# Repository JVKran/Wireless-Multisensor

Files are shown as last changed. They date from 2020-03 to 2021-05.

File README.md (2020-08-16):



# Wireless Multi-Sensor
ESP8266's are great! They are suited for an endless amount of fun projects. However, when you want to create small wireless modules, they are not so great; they consume way too much power and are pretty bulky. That's where this Wireless Multisensor comes into play; it features a sleep current of 50uA resulting in a lifetime of 3 years when using a CR123A battery! This is possible due to the use of an ATtiny85V with energy efficient components, sensors and libraries. Furthermore, it has a neat PCB and casing that really finishes it off!

All in all this sensor measures temperature, humidity, pressure, motion and illuminance. While that's already impressive, it's also possible to connect a switch to the JST-Connector to furter increase possibilities and tweakability. Hence one can connect a reed switch to determine the state of windows or doors, a button to toggle the lights in the room or a vibration sensor to detect movement of the sensor. These features will now be examined further.

## Features
### Years of worryless use
The ATtiny85V with a minimum voltage of 1.7V and a clock set at 1MHz paired with the abovely mentioned components and some very efficient libraries, results in a current draw of 52uA. Based on a 1500mAh CR123A this means the battery has got to be changed every (1500mAh / 0.052 =) 28800 hours or 1200 days or 3.3 years! Note that this depends on how often doors/windows are closed/opened, motion is detected, measurements should be made, etc. I therefore don't recommend changing the intervals of climate and illuminance measurements.

### Climate
The Multisensor is equipped with a BME280 that's able to measure temperature, relative humidity and pressure. The interval at which these are measured and transmitted can easily be changed. Due to the encredibly well engineerd chip, measurements are very accurate. The temperature and humidity have an absolute accuracy of 1% while the pressure reading has an absolute accuracy of 3%. Further specifications can be read in the [datasheet](https://www.bosch-sensortec.com/media/boschsensortec/downloads/datasheets/bst-bme280-ds002.pdf). By using my [Forced-BME280 library](https://github.com/JVKran/Forced-BME280) the chip only uses 0.25uA when in sleep. That's impressive!

### Motion
An AM312 Passive Infrared sensor is used; these are small, only draw 16uA and dont suffer from false positives. The detection distance is approximately 3-5m depending on light circumstances. As if that isn't impressive yet, the detection is practically instant since an interrupt is used. By disabling interrupts after the interrupt occured, and waiting for the voltage to settle at the pin, false positives are practically impossible. All in all this is a solid but small PIR-Sensor perfectly suited for this kind of use.

### Reed Switch
Since it could be useful to detect the position of a door or window, one pin is exposed through a JST-Connector. This is done so one can also use a button to trigger a transmission; hence it doesn't have to be wired to a reed switch. A button to toggle lights or a vibration sensor to fire the alarm are all possibly useful scenario's. It's important to note that current draw is very limited; due to the small amount of available energy, the +-rail of the JST-Connector is placed in series with a 1M resistor. Hence a button with a LED is not possible. Otherwise the battery would be dead in no time.

### Illuminance
Last but not least the Multisensor is also equipped with a BH1750 to measure illuminance. By only using my [OneTime-BH1750 library](https://github.com/JVKran/OneTime-BH1750), the chip is incredibly energy efficient; it only draws 6uA when in sleep making it ideal for a wireless multisensor like this. This mode results in an accuracy of 4lx. That's totally acceptable since a measurement in High Res mode, with an accuracy of 1lx, would take 160ms; that's a little long which would impact the battery life significantly. All in all it's way more efficient than a traditional LDR making it perfect for this Wireless Multisensor. Further specifications can be found in the [datasheet](https://www.mouser.com/datasheet/2/348/bh1750fvi-e-186247.pdf).

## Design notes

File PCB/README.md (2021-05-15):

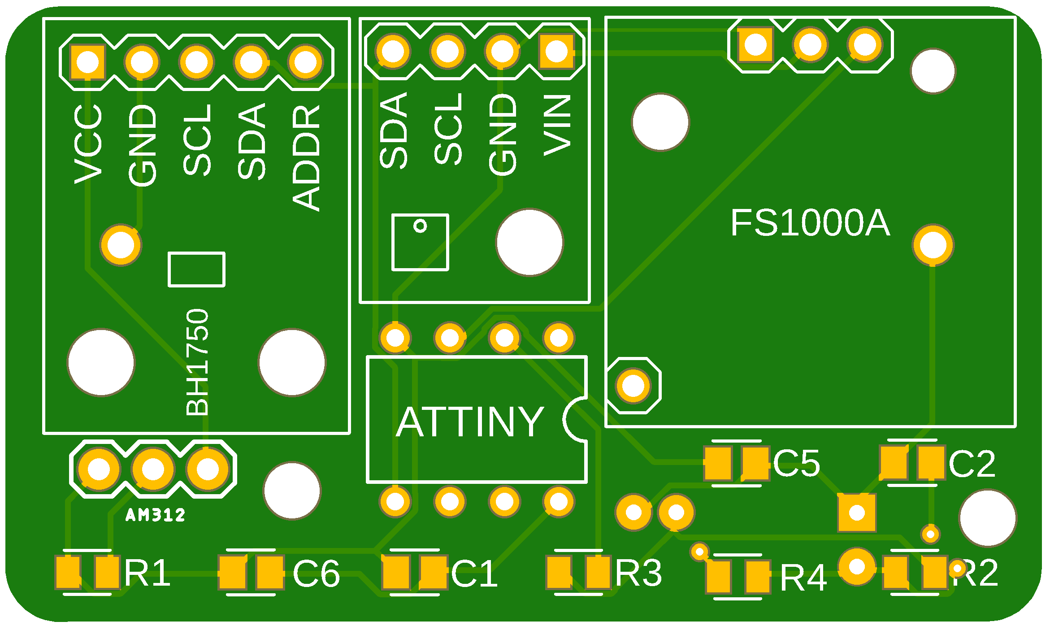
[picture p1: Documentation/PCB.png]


# How to use
These 3 folders contain everything needed to manufacture the PCB. Some manufacturers like JLCPCB requires you to zip them. Just a matter of copy paste to order your own Wireless Multisensor PCB's!

# Warning!
The PCB is not functional as of now. There's a very obvious error that I'll correct later on (probably this summer).

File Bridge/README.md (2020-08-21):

# Bridge
The bridge functions as a, you guessed it, bridge between the wireless sensor module and the MQTT broker. Hence, it needs to have a 433Mhz receiver and be able to connect to an MQTT Broker. That's exactly what's happening here. 

## How to use
There are several ways to use this program. One can flash this code on an ESP-01, connect a SRX882 and just put it somewhere. However, when you already have an ESP8266 running somewhere, you could easily just copy this code with additional benefit a very easy to use MQTT client. That's what I've done with my [Central Hub](https://github.com/JVKran/Sensor-Module). If you're planning on doing so, I strongly recommend you to read the [documentation](/Documentation). I use some pretty advanced principles that aren't very Arduino friendly.

If you're not, and just want to use this code as-is, it's a lot easier to setup. Just flash the code on your desired microcontroller (ESP-01, D1 Mini, NodeMCU V3, etc.), connect to the 'Wireless-Multisensor Bridge' Acces-Point, navigate to '192.168.4.1' and enter your credentials. This is a one-time process; after this is done, the credentials will be stored in the EEPROM. For the more visual people, I also made a [video](https://youtu.be/CQGhy87DgMU) on how to set it up. When it's connected to your network, the interface will remain available; however, the IP-address has changed.

## Flashing
Since there is infinte amount of possible mirocontrollers, I won't go through all required steps to upload the code. For a D1 Mini or NodeMCU V3 for example, it's just a matter of flashing it via USB while for an ESP-01, it's a matter of using an FTDI programmer. 

What however is the same for all possible hardware/software combinations, is what libraries have to be installed. They are listed below.
- [ESP8266WiFi](https://github.com/esp8266/Arduino/tree/master/libraries/ESP8266WiFi); library needed for connection with Wifi-Network.
- [PubSubClient](https://github.com/knolleary/pubsubclient); an MQTT-Client library.
- [Manchester](https://github.com/mchr3k/arduino-libs-manchester); a Manchester Encoding library.

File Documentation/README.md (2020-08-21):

# Doxygen
There is Doxygen documentation available for every function and class. All you have to do is go to the [documentation on my site](https://jochemvk.duckdns.org/doxygen/Wireless-Multisensor/html/annotated.html) or run ```doxygen Doxyfile```.

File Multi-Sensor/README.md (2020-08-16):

# Multi-Sensor
This directory contains everything that's needed to setup your very own Wireless-Multisensor. Everything is taken care of; wiring, compiling and flashing. If anything is unclear or you're having trouble with anything, feel free to contact me and I'll do my best to resolve the issue.

## How to use
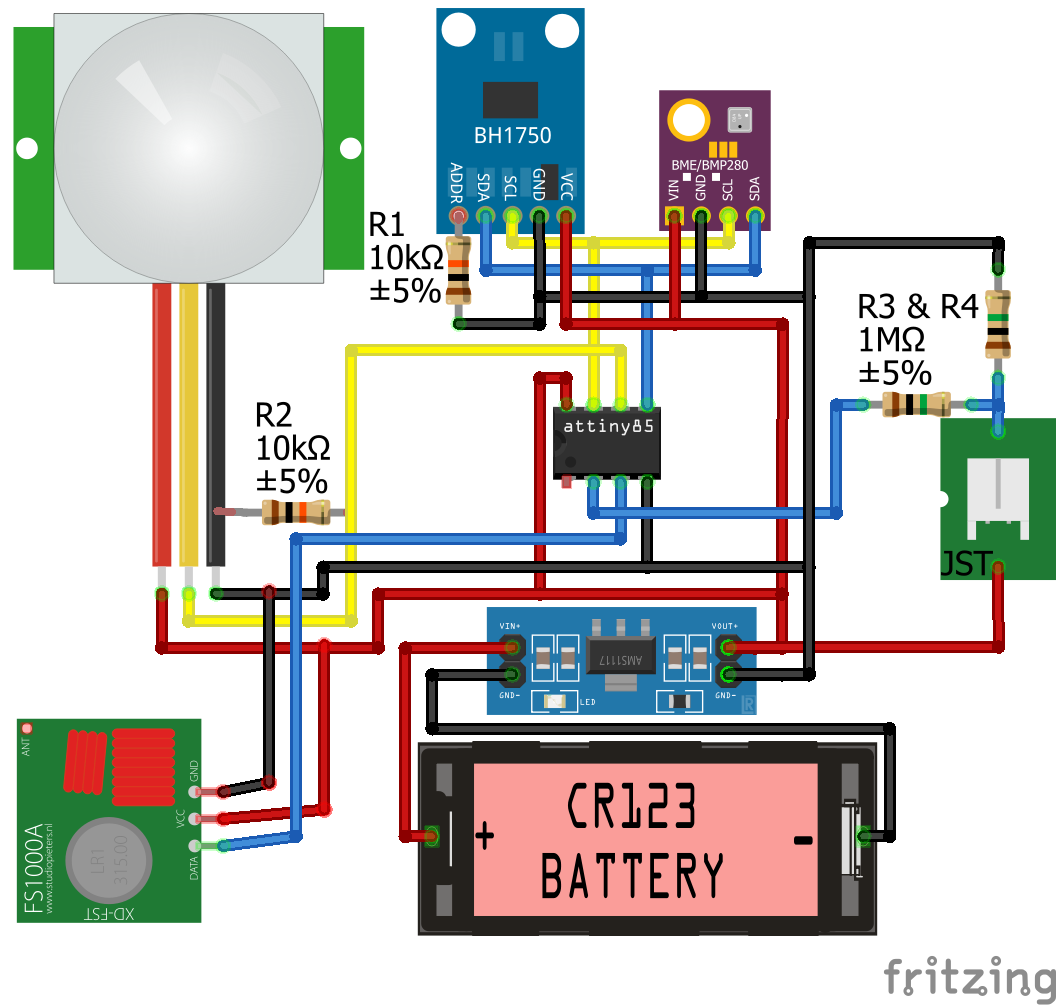
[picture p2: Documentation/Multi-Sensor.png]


Well, in contrary of the bridge, the amount of ways to use it, are pretty small; it just does what it does... The code above should be flashed to an ATtiny85V running at 1MHz with the Brownout Detector enabled at 1.8V. After that has been done, one can plug it in a breadboard to recreate the [schematic](Documentation/Multi-Sensor%20Schematic.png) or solder it onto the [PCB](/PCB). 

For people who arent used to reading schematics, I also made a [Fritzing Diagram](/Documentation/Multi-Sensor.png) that's visible on the right. For stability reasons, I strongly recommend everyone to use the PCB for pronlonged periods of use; it's way more stable in operation. Only use a breadboard for testing purposes and verifying wether or not the flashing was succesful.

## Flashing
The codebase utilizes [SpenceKonde's ATTinyCore](https://github.com/SpenceKonde/ATTinyCore). Hence that has got to be installed. The instructions on the linked page are very clear and easy to follow. Once that has been installed, there are also some libraries needed to compile the code. Hence, the following libraries have to be installed:
- [Forced-BME280](https://github.com/JVKran/Forced-BME280); a small and efficient library for the BME280.
- [OneTime-BH1750](https://github.com/JVKran/OneTime-BH1750); a small and efficient library for the BH1750.
- [Manchester](https://github.com/mchr3k/arduino-libs-manchester); a Manchester Encoding library.

Once that's all downloaded and installed, one is almost ready to compile and flash the code. There are only a couple more settings to alter to make sure the mentioned battery life is possible and operation is stable.
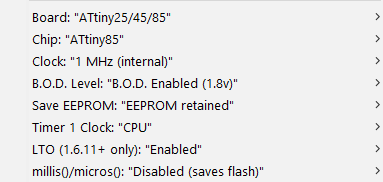
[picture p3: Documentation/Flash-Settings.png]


- ATtiny85 has got to be selected.
- Clock should be set at "1MHz internal"
- B.O.D. Level should be set at 1.8V
- millis()/micros() should be disabled

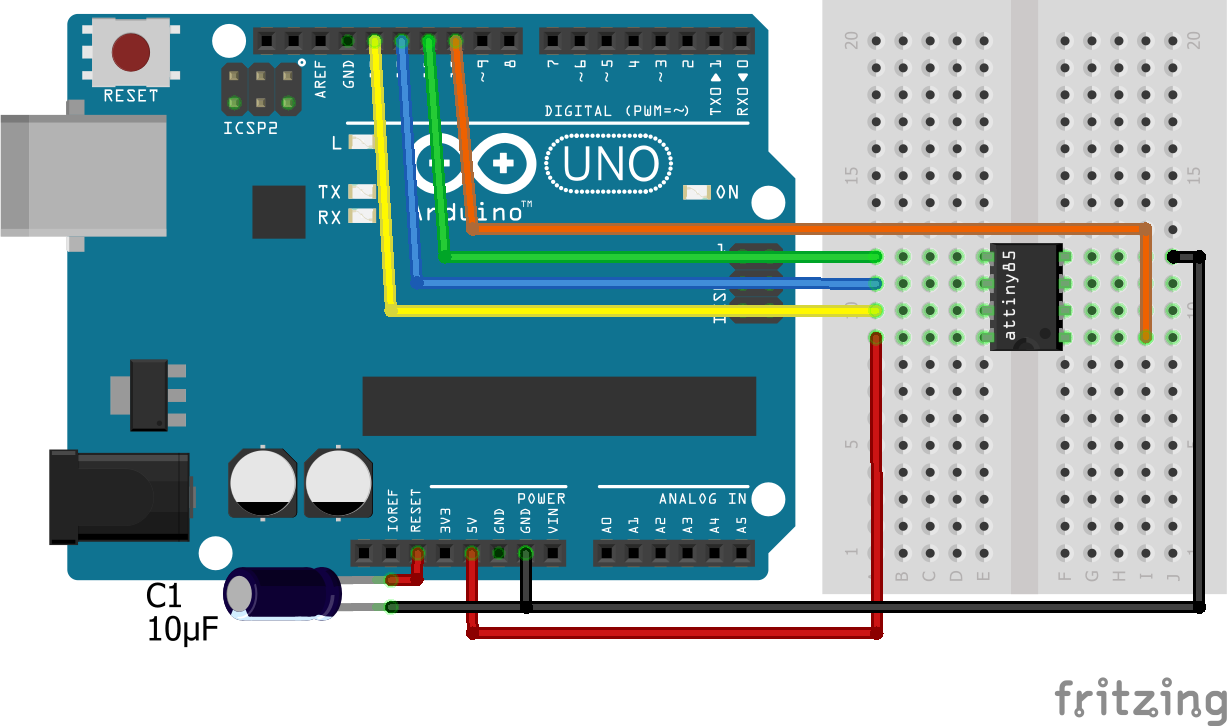
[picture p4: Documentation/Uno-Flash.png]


You're now ready to flash the code! By uploading the Arduino ISP sketch to an Arduino UNO, wiring the ATtiny85V to the Arduino UNO as in this schematic and uploading the Multi-Sensor.ino to the port to which the Arduino UNO is connected, the ATtiny85V is flashed and ready to use! I strongly recommend recreating the abovely visible schematic on a breadboard and setting everything up as you're willing to use it in the future to verify that everything works as expected. Don't be scared when it stops working after several days; that instability is caused by the long jumper wires on the breadboard and will not occur when everything is solderd onto the PCB.

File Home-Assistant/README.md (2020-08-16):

## Home-Assistant
To be able to let the Wireless-Multisensors talk to, for example, Home-Assistant, one would need to use the Bridge to 'bridge' the 433MHz messages to MQTT. This can be done by using the code in the [Bridge Directory](/Bridge). Further information can also be found there. It boils down to two possibilities; using a dedicated ESP or letting the code run on an already in use ESP. Anyhow, the code and principle is the same. 

### Configuration
For the Wireless-Multisensors to show up in Home-Assistant, one has to change the configuration. The required code for configuring the Wireless Multisensor is verly limited and can be found in the [configuration.yaml](/Home-Assistant/configuration.yaml) file. It's just a matter of copy-paste. It is however, worth noticing that the id of the Wireless-Multisensor defines the topic the measurements are published on. Hence it's important to keep track of what id's are already in use. Two Wireless-Multisensors with the same id doesnt't mean they won't work anymore; they'll just end up as one sensor which isn't what we want.

### Lovelace UI
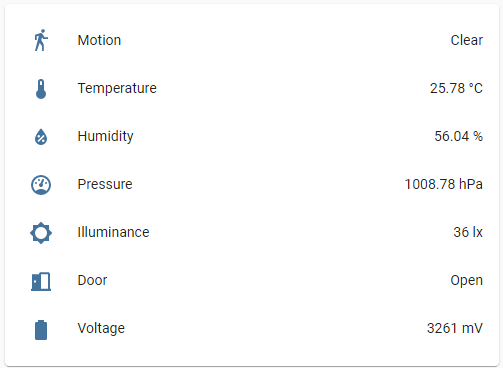
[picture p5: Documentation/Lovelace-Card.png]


I trust most of you to know how to integrate the entities into the Lovelace UI but for starters there's an example in [lovelace.yaml](/Home-Assistant/lovelace.yaml); just copy and paste it in the code editor of a card like here. Since you could have multiple sensors, and every entity has got te be unique, the id of the sensor has to be part of the entity_id. While not so user friendly, it's the only option.

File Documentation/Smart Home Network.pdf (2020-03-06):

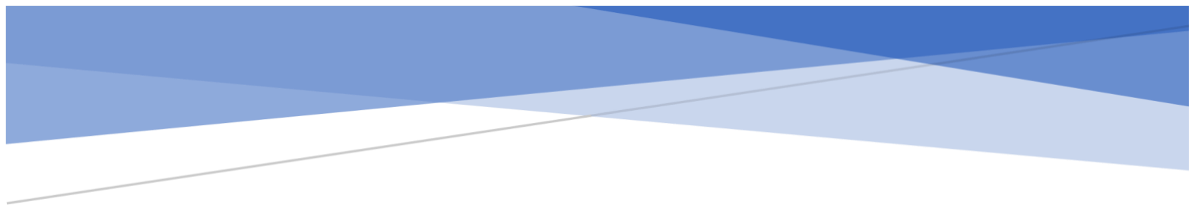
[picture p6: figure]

# HOME NETWORK

## Smart and centralized

### Jochem van Kranenburg

6-3-2019

### Content

This document is used to list and elaborate all possibilities for a smart home network. A Home Network in this context is the network used to connect all sensors and actuators to the central Home Automation system which in this case is Home Assistant.

## Contents

## Preambule

The current setup of my Home Automation system consists of one Raspberry Pi 3B+ running Home Assistant and a MQTT Broker. Furthermore, there is one very powerful sensor and actuator node consisting of a Wemos D1 Mini (160MHz) with an Infrared transmitter, 433MHz transmitter, RGB-Led, buzzer and motion sensor.

This node controls several 433MHz sockets and the speaker for the television. Since I have been tinkering with and developing my Home Automation system I was reaching the current limits. That’s the reason I wanted to create several battery powered sensor nodes. Furthermore, the large amount of wifi conntected devices was taking its toll on my router.

Hence, the goal is to setup a wireless network to which low power devices can be connected. Since they have to be low power, and wifi generally isn’t low power, we’ll assume there has to be one master node that communicates with the Home Automation system.

## Communication possibilities

There are several standards being used for communicating with sensor and actuator nodes. These will all be listed in this chapter.

### Message Queue Telemetry Transport

Since I am wanting to create several battery powered devices, this protocol does not apply. The ESP8266’s don’t consume a lot of power when in deep sleep, but they need to connect to the router, setup the connection with the broker and then transmit the message. This takes quite a lot of time and consumes a lot of power.

### HTTP

The HTTP POST and GET requests have more overhead, more latency and less reliability than MQTT Messages¹
. Furthermore HTTP is made for large amounts of throughput; that’s not what we’re after. And since this also requires internet connection, a lot of power is wasted while connecting.

### Zigbee

Since Zigbee modules are pretty available, (https://www.sparkfun.com/pages/xbee_guide) have low standby power consumption (30 uA) and are fire-and-forget, these are pretty usable modules. However, they come at a price of roughly €20,-. For a network of nodes this can get expansive very quickly…

### Bluetooth

Having worked with Bluetooth and knowing it can be used in a fire-and-forget manner, this immediately came to my mind. The range is not that good, but should be enough to remain paired and transmit data. However, retain paired, sounds like power consuming. I grabbed my multimeter, and yes, it is…

State | Current draw (mA)
Pairing | 40
Pared | 20
Standby | 2.0
This is not an option; 2mA standby current is way to much.

### NRF24

This module is also worth mentioning since it has an IRQ pin that turns high when data is received; this creates the possibility to wake the microcontroller on data reception. However, for the module to listen, it has to be turned on. It then uses 13mA. We actually don’t necessarily have to be listening though; only transmitting is needed. Unfortunately even the NRF24L01+ with external antenna can’t reach the attic.

### ASK

Our goal perfectly matches with what Amplitude Shift Keying is made for; low power small data transmission. Furthermore, these modules are very cheap and have a good range. Well… Actually, the SRX882 has a good reception range. Every transmitter is good.

Since they barely use any current while in standby and de protocol is fire-and-forget, this is going to be our choice.

## Sensors

Since this node is meant as multi-sensor in as much rooms as possible we have to think of what sensors to use.

### Climate

One very useful thing to monitor is the climate; temperature and humidity specifically. The DHT11 consumes about 50uA and the DHT22 20uA. However the BME280 only uses 0.2uA when in sleep mode.

I’d really like to monitor air quality too, but that would make the module more expensive. Furthermore, if you really want accurate readings (which I do), you should actually go for something in the PMS series; for example the PMS5003 or PMS7003. These consume a lot of power though. That’s more something for the master module.

### Movement

It’s also useful to measure movement to, for example, turn lights on when there is movement and it’s dark. Hence an LDR would also be convenient.

When extended for alarm system use, a vibration sensor can be useful to determine whether or not the device has been picked up or moved.

### Windows

It can be useful to monitor the state of windows as well. Let’s assume it’s 24 degrees Celsius in a room and the windows are opened. After 2 hours of cooling it’s 18 degrees Celsius so now the windows can be closed. Then a message can be sent to one of the inhabitants.

And when everyone leaves the home, a message can be sent that a window has been left open.

## Actuators

Since actuators are most likely being controlled by the Home Automation system and the module then has to continuously listen, we aren’t going to embed any actutators.

## Nodes

### Living room

The living room node consists of the following components:

The movement sensor is used to alert the Home Automation system in case of movement. Based on the current state of the alarm, the alarm triggers or doesn’t. Furthermore, based on the state of the light intensity, the Home Automation system determines if the lights should turn on.

The Home Automation system is notified when the vibration sensor detects movement. If the alarm is enabled, it now triggers.

Furthermore, it’s wanted to measure the battery voltage and thus percentage.

A button could come in handy for single short actions; maybe to light up an OLED to show climate information?

### Hallway/Stairs

Actually the only reason the node should be near the stairs is to turn on the light when someone is trying to go down the stairs. Hence, it should only consist of an AM312, microcontroller, STX882 and CR2032.

But, if the AM312 could be facing the stairs and the rest of the node towards the hall maybe a BME280 could be of use as well? I don’t really think so; they’re also in the bedrooms…

### Bedrooms

Temperature and humidity are interesting in bedrooms since they have a significant impact on the quality of sleep. So let’s throw in a BME280.

Since this climate is so important, the node can help control this climate. Telling when the window should be opened and closed and notifying when the window has been left open and everyone’s gone.

Assuming that I’m going to make a bed occupancy sensor in the future, it’s also interesting to measure movement and light to turn the light on if there’s movement, no one is in the bed and it’s dark.

This node assumes there’s a smart alarm clock with weightsensors (load cells with HX711) and button to operate the (by a sonoff switched) light.

Type | Component
Temperature | BME280
Humidity | BME280
Air pressure | BME280
Movement | AM312
Vibration | HDX
Light | LDR
Transmitter | STX882
Battery | CR2032
Button | Button
OLED | SSD1306
Type | Component
Temperature | BME280
Humidity | BME280
Air pressure | BME280
Movement | AM312
Light | LDR
Battery | CR2032
Transmitter | STX882
Window sensor | Reed switch
OLED | SSD1306

## Bridge

As discussed, we need to have a bridge between the STX882 and the Home Automation system. This can essentially be done in two ways; one could add an SRX882 to receive the 433MHz signals directly to the device running the Home Automation system. One could also create a separate device that functions as a bridge between 433MHz and some popular other (possibly Wi-Fi enabled) protocol.

In this case the choice has been made to use some kind of ESP that listens for 433MHz signals and forwards these to the Home Automation system using Message Queue Telemetry Transport (MQTT).

## References

1- Naik, N. (2017). Choice of Effective Messaging Protocols for IoT Systems: MQTT, CoAP, AMQP and HTTP. Geraadpleegd van https://researchportal.port.ac.uk/portal/files/12197128/IoT_Messaging_Protocols_Naik.pdf

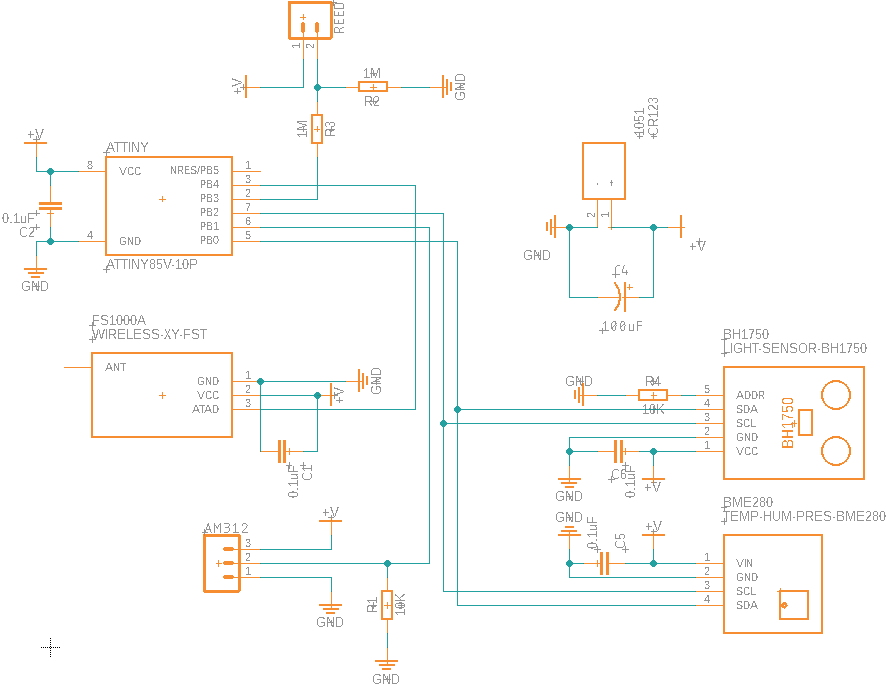
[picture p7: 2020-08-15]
Documentation/Multi-Sensor Schematic.png

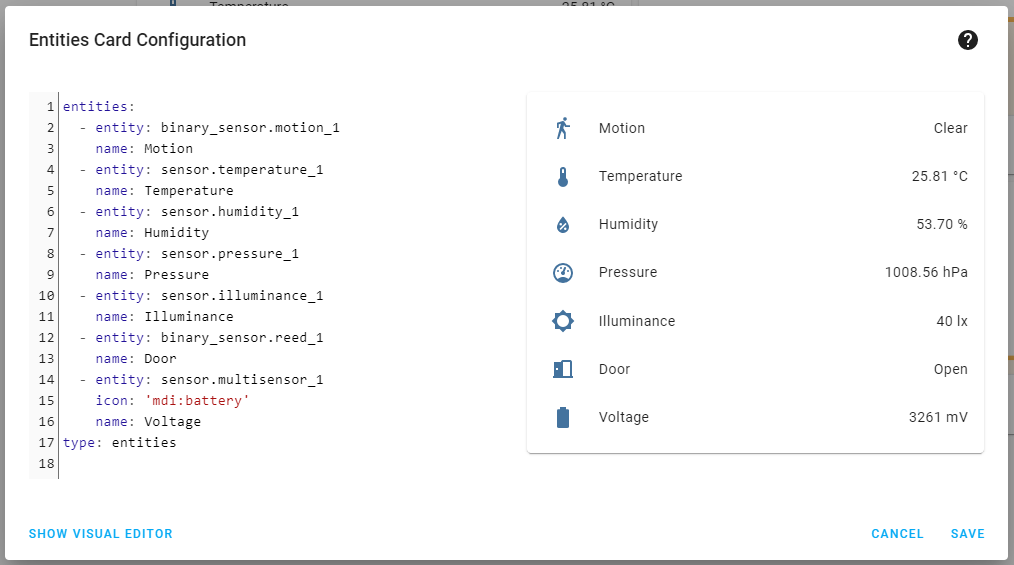
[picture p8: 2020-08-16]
Documentation/Lovelace-Configuration.png

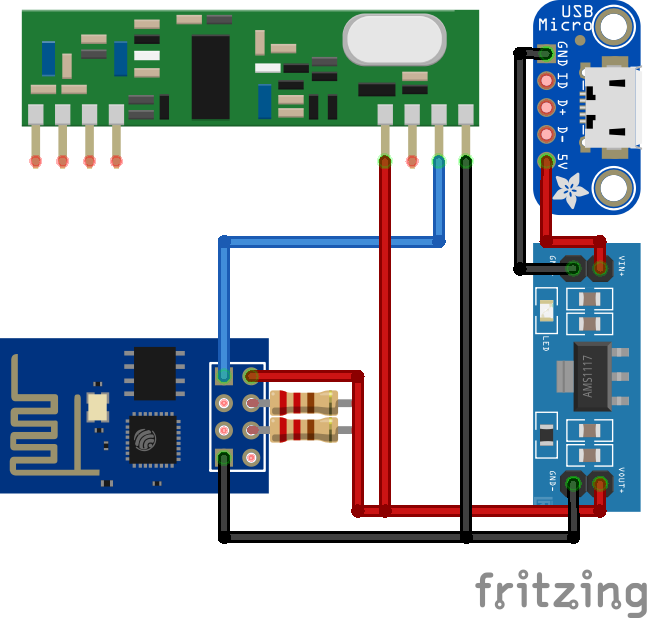
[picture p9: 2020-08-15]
Documentation/Bridge.png

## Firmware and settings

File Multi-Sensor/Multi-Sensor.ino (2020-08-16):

/* Power Consumption
The ATtiny has the WDT enabled which uses 4uA. Furthermore, the AM312 is 
continuously drawing 13uA, the BME280 draws 0.25uA when in sleep and the BH1750 
draws 6uA in sleep. Furthermore, there are a couple of capacitors resulting 
in a leakage current.

This sums up to 50uA which corresponds to the readings of my multimeter.
With a CR2032 this results in ((230mAh / 0.050mA) / 24 =) 1250 days of
worry-free wireless use.

However, that is without taking the STX882 into account, which isn't fair...
During transmission it draws 34mA... In sleep it's only 0.1uA; no problem there.
The transmission of 1 bit takes (1/2400 =) 416uS. 11 elements * 8 bits = 88 bits
to transmit. That results in (416 * 88 =) 36 milliseconds of transmission.

A 15 minute period results in the following calculation;
900s @ 50uA + 0.036s @ 34000uA = 45000uAs + 1224uAs = 30924uA / 900 = 52uA on average.
This results in an expected lifetime of (1500mAh / 0.052 =) 28800 hours (1200 days).  

That's pretty impressive!

Futhermore, it's very important to set the clock of the ATtiny at 1MHz internal
and enable the Brownout Detection and set it at 1.7V for the ATtiny85V. Don't
forget to burn the bootloader with these changed parameters!

As another flash saving method, millis() can be disabled from te same dropdown
menu; it's not used anyway.
*/

#include <forcedClimate.h>		// Small and efficient BME280 Library
#include <BH1750.h>				// Small and efficient BH1750 library

#include "powerSaving.hpp"
#include "passiveInfrared.hpp"
#include "Climate.hpp"
#include "Light.hpp"
#include "Reed.hpp"
#include "manchesterTransmitter.hpp"

constexpr uint8_t sda 			= PIN_B0;
constexpr uint8_t scl 			= PIN_B2;
constexpr uint8_t transmitPin 	= PIN_B4;
constexpr uint8_t reedPin 		= PCINT3;
constexpr uint8_t pirPin 		= PCINT1;
constexpr uint8_t multiSensorId = 1;

ManchesterTransmitter transmitter = ManchesterTransmitter(multiSensorId);
PassiveInfrared pir = PassiveInfrared(pirPin, transmitter);
Reed reed = Reed(reedPin, transmitter);
PowerManagement power = PowerManagement(transmitter, PM_15MIN);

ForcedClimate bme = ForcedClimate(TinyWireM, 0x76, false);
Climate climate = Climate(bme, transmitter, CLM_15MIN);

BH1750 lightSensor = BH1750();
Light light = Light(lightSensor, transmitter, LHT_15MIN);

ISR(PCINT0_vect){
	cli();						// Disable interrupts to prevent bouncing.
	pir.sensedMotion();
	reed.sensedChange();
}

void setup() {
	transmitter.begin(transmitPin, MAN_2400);

	pir.begin();
	reed.begin();
	light.begin();
	climate.begin();
	power.begin();
}

void loop() {
	climate();					// Measure light temperature, humidity and pressure when it's time to do so.
	light();					// Measure light intensity when it's time to do so.
	power();					// Update voltage when it's time to do so.

	reed();						// so the voltage can settle resulting in an accurate digital reading.
	pir();						// Handle the possible occurence of an interrupt. Fist climate, light and power are taken care of.

	transmitter();				// Transmit data if data has changed.
	sei();						// Enable interrupts again.
	power.sleep(PM_8SEC);		// Sleep for 8 seconds or shorter when an interrupt occurs.
}

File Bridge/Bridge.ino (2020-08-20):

#include <ESP8266WiFi.h>
#include "MqttClient.hpp"
#include "SensorBridge.hpp"

// Can be left blank for wireless setup; only interesting for the ones that are embedding the code in an already existing project.
#define SSID ""
#define WPA ""
#define BROKER ""
#define TOPIC "/raspberrypi/homeassistant"

WiFiClient espClient;                   // Can also be passed to other instances.
MqttClient client(SSID, WPA, BROKER, TOPIC, espClient);
SensorBridge sensorBridge = SensorBridge();

void callback(char* topic, byte* payload, unsigned int length) {
    static String message;
    for (int i = 0; i < length; i++) {
        message.concat((char)payload[i]);
    }
    client.notifyListeners(message, topic);
    message = "";  
}

void setup() {
    Serial.begin(9600);
    client.begin();

    sensorBridge.begin(3, MAN_2400);
	sensorBridge.addListener(client);   // Let client listen to sensor readings
}

void loop() {
    client();                           // Handle incoming sensor readings and publish them
    sensorBridge();                     // Handle incoming transmissions from Wireless Multi-Sensors.   
}

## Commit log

2020-02-16 Created battery efficient module
2020-03-11 Battery-Powered Motion Sensor
2020-03-11 Working Temperature Broadcast
2020-03-11 Temperature, Humidity and Pressure Broadcast
2020-03-13 Fully working wireless sensor
2020-03-14 Added GPIO-Less Voltage Meter
2020-03-15 Added Documentation
    [Multi-Sensor.fzz, Receiver.fzz]
2020-07-03 Enabling ADC after sleep
2020-07-09 Fixed bug when brownout has occured
    [Multi-Sensor.ino, powerSaving.cpp]
2020-08-14 Added light sensor and reed switch
2020-08-14 Added Printed Circuit Board
    [copper_bottom.gbr, copper_top.gbr, drill_1_16.xln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]
2020-08-15 Extended Documentation
    [Bridge.fzz, Multi-Sensor.fzz, Receiver.fzz]
2020-08-15 Rewrote constructor to begin() and added Doxygen. Doing things in the constructor can cause undefined behaviour in the way Arduino is implemented so using begin() ensures proper functioning.
2020-08-16 Added Flash Schematics
    [Uno-Flash.fzz]
2020-08-16 Changed Orientation
    [Uno-Flash.fzz]
2020-08-16 Added component values
    [Multi-Sensor.fzz]
